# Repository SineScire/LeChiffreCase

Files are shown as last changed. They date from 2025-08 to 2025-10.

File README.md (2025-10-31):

<a href="https://github.com/SineScire/LeChiffreCase">LeChiffreCase</a> © 2025 by <a href="https://github.com/SineScire">SineNomen</a> is licensed under <a href="https://creativecommons.org/licenses/by-nc-sa/4.0/">CC BY-NC-SA 4.0</a>

# LeChiffreCase
A case for the Le Chiffre keyboard with a gasket mounted switchplate

There are multiple versions of the gaskets:
* Soft: Switchplate flexes with the press of a single key
* Medium: Switchplate flexes with the press of multiple keys
* Hard: Switchplate hardly flexes with the press of multiple keys

Check out the manual [here](https://github.com/SineScire/LeChiffreCase/blob/709f2b51f192e5b002fa32b0e5fa310748ea253c/Manual.md)

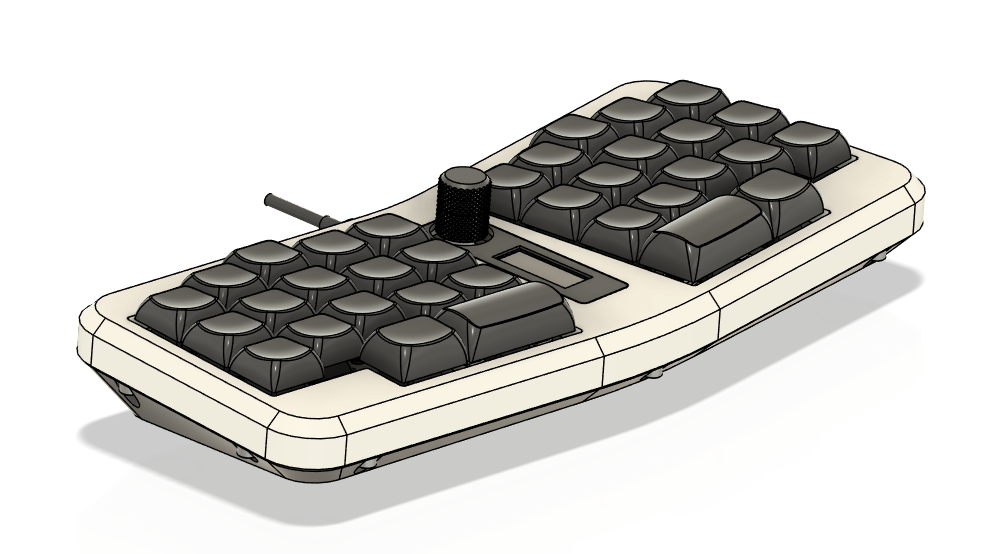
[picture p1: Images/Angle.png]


## Credits
* [Tominabox1](https://github.com/tominabox1/Le-Chiffre-Keyboard) for the original PCB design
* [Sporkus](https://github.com/sporkus/le_chiffre_keyboard_stm32) for the stm32F072 PCB design
* [Keycapsss](https://keycapsss.com/) for providing the PCB

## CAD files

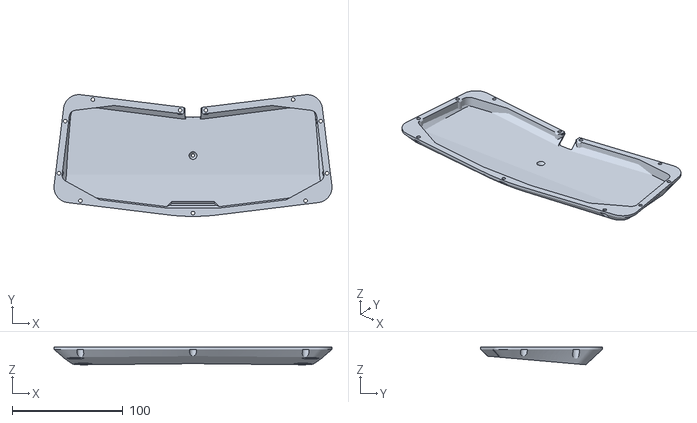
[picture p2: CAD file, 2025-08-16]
Files/BottomHousing.stl
251.0 x 110.0 x 15.9

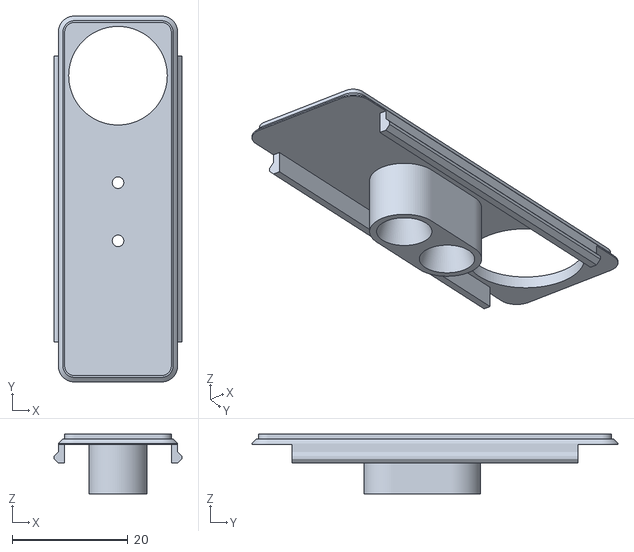
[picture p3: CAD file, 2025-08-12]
Files/InsertKnobLights.stl
22.0 x 63.1 x 10.3

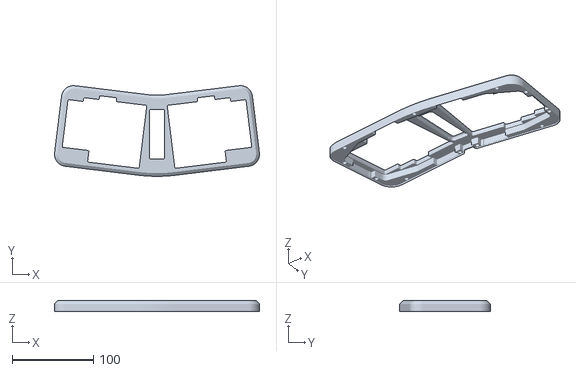
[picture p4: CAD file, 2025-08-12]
Files/TopHousing.stl
253.0 x 111.9 x 13.0

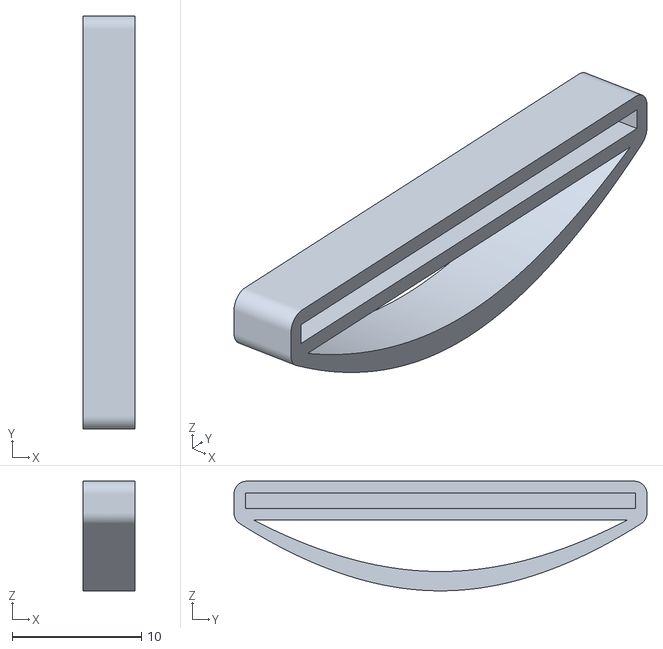
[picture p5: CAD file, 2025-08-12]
Files/GasketSoft.stl
4.00 x 32.0 x 8.50

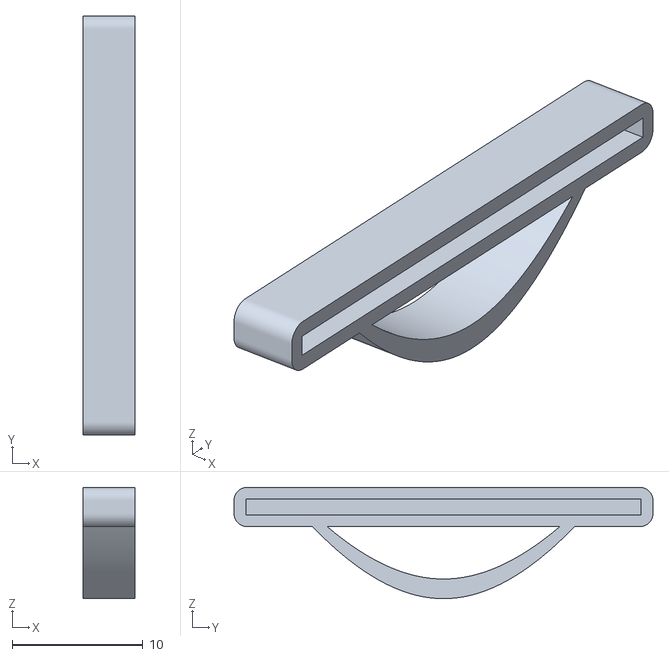
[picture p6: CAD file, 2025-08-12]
Files/GasketHard.stl
4.00 x 32.0 x 8.50

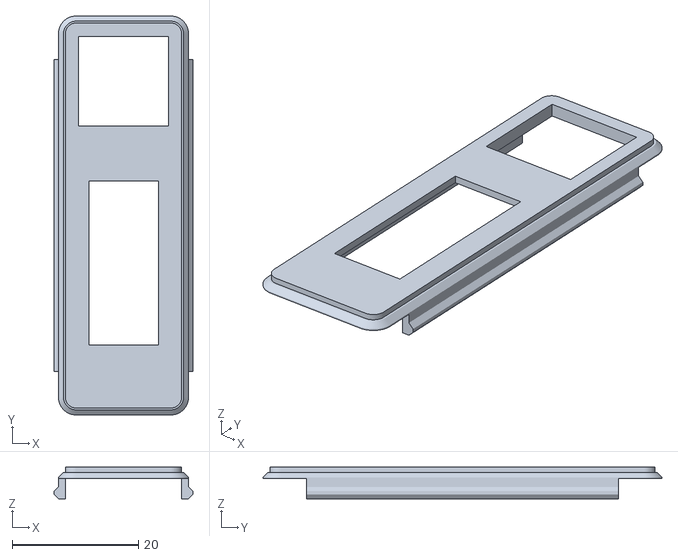
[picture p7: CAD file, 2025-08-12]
Files/InsertSwitchScreen.stl
22.0 x 63.1 x 5.00

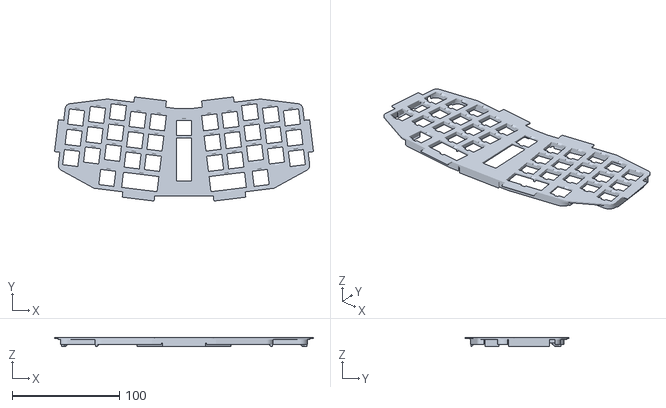
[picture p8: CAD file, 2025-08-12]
Files/Switchplate.stl
241.4 x 97.1 x 8.10

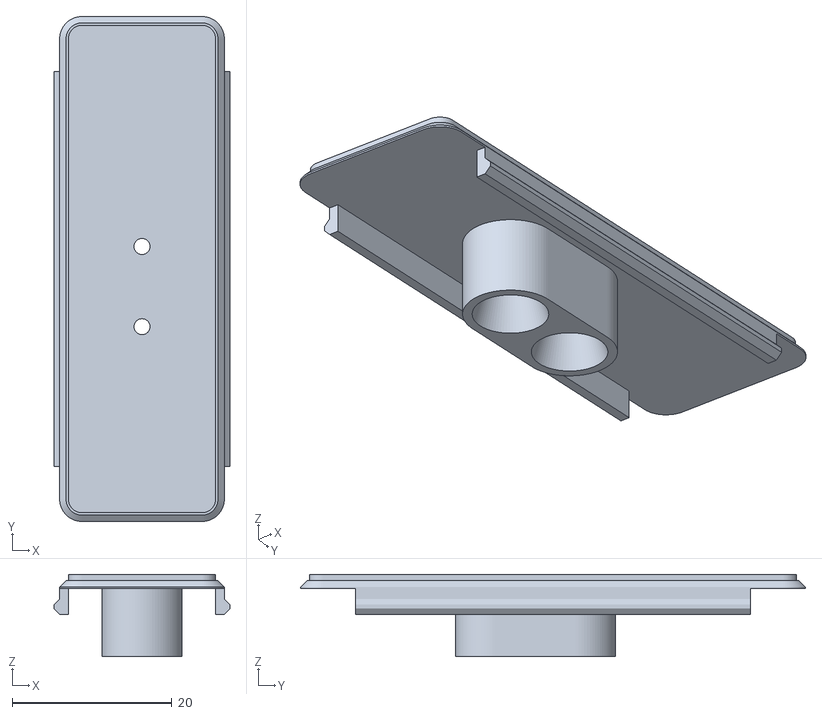
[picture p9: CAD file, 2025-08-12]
Files/InsertLights.stl
22.0 x 63.1 x 10.3

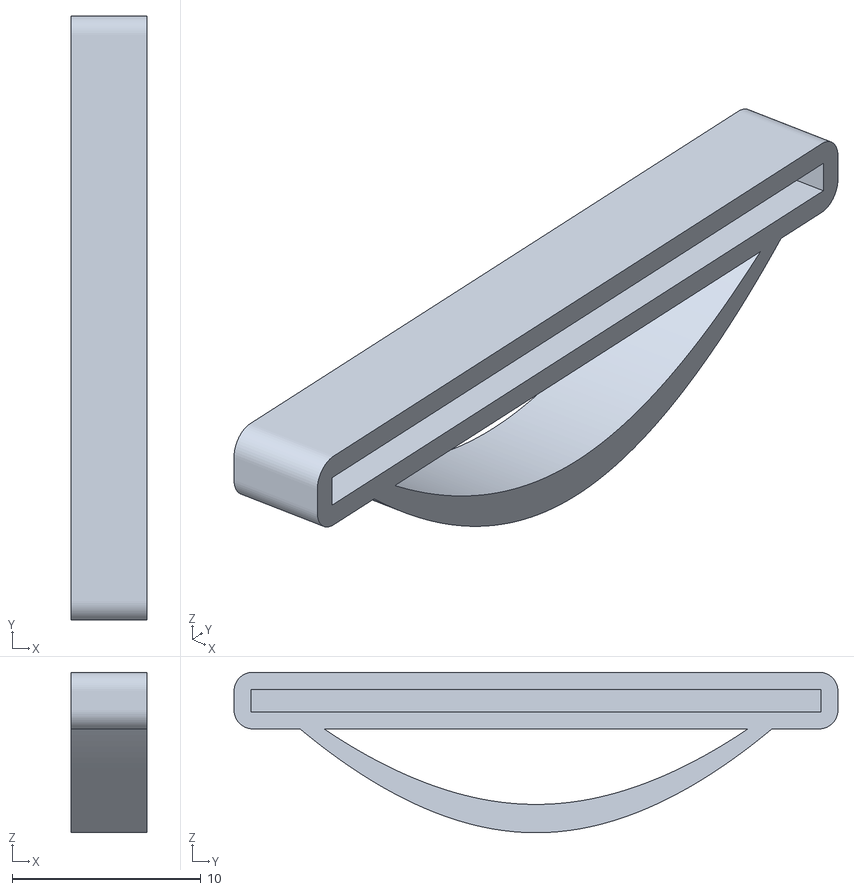
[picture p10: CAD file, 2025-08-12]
Files/GasketMedium.stl
4.00 x 32.0 x 8.50

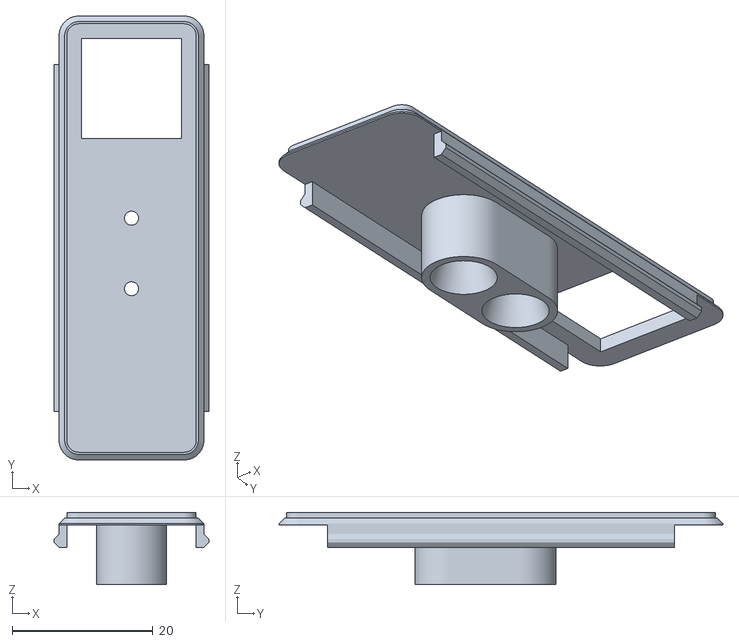
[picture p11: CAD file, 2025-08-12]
Files/InsertSwitchLights.stl
22.0 x 63.1 x 10.3

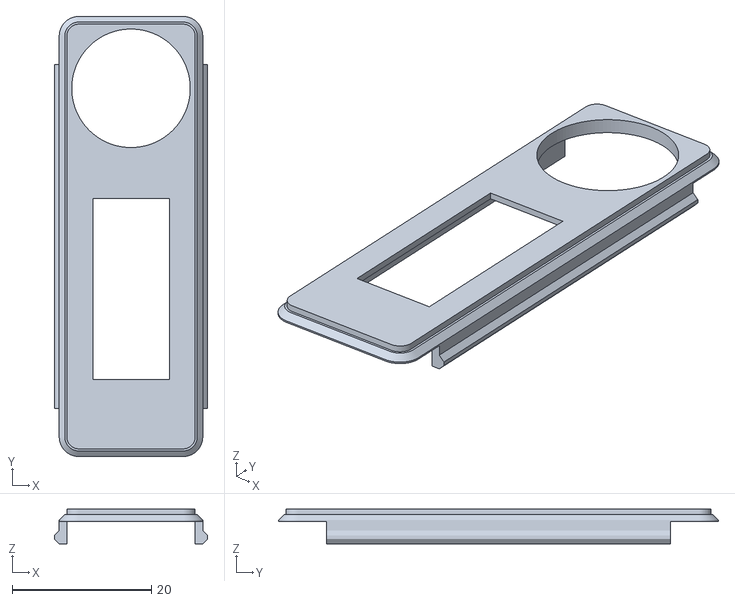
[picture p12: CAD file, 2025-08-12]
Files/InsertKnobScreen.stl
22.0 x 63.1 x 5.00

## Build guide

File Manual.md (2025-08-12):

## BOM

| Part | Quantity | Description |
| ---- | --- | --- |
| Top Housing | 1x | 3D printed part |
| Bottom Housing | 1x | 3D printed part | 
| Switchplate | 1x | 3D printed part | 
| Insertplate | 1x | A window plate for the screen/knob/lights |
| Gaskets | 6x | 3D printed with flexible filament around 95A hardness |
| m3x4mm Threaded Insert | 11x | Brass inserts for the top housing |
| m3x6mm Sockethead Screws | 11x | To fasten the top and bottom housing |
| Rubber feet | 4x | 2mm thick rubber feet with a diameter of 15mm |
| Soldering iron | 1x | To insert the threaded inserts |

## Printing the parts
* Suggested printing orientation for the parts
* The gaskets are printed with flexible filament with a hardness around 95A
* No supports should be needed to print these parts

| Top housing | Bottom housing | Switchplate |
| --- | --- | --- |
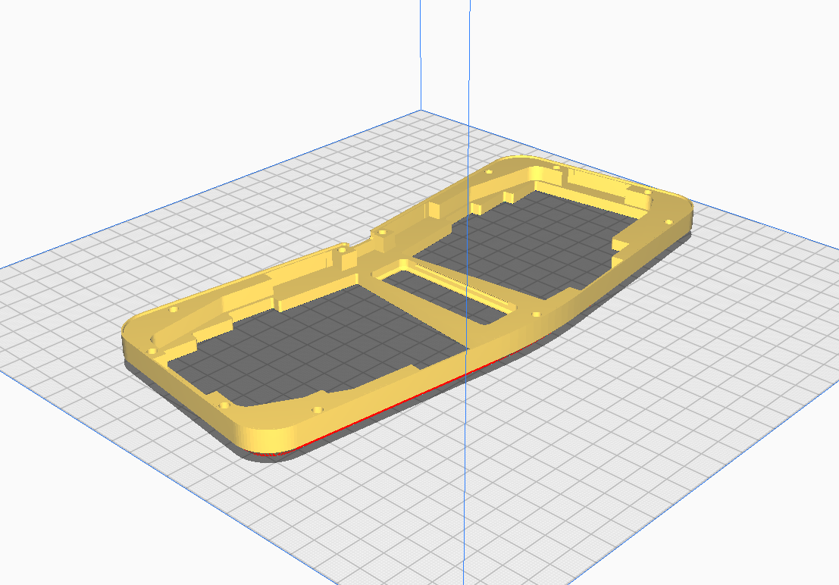
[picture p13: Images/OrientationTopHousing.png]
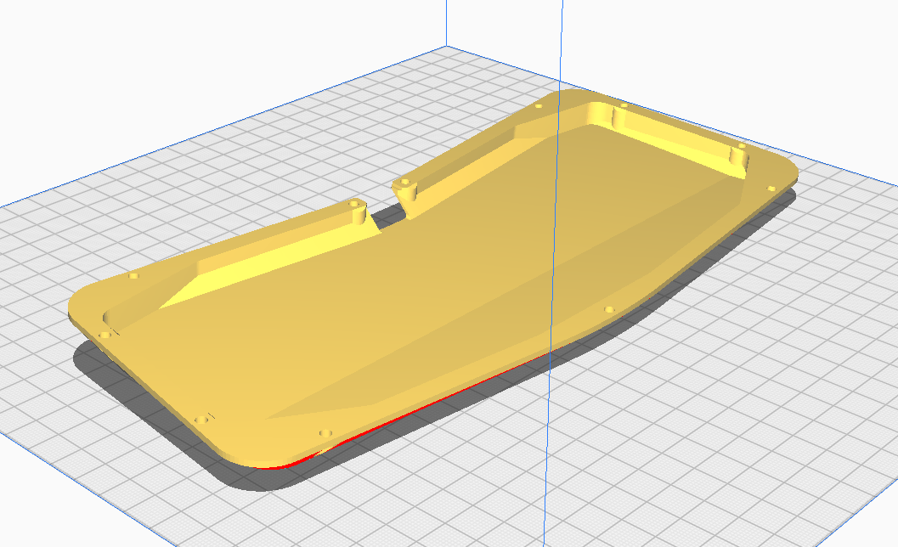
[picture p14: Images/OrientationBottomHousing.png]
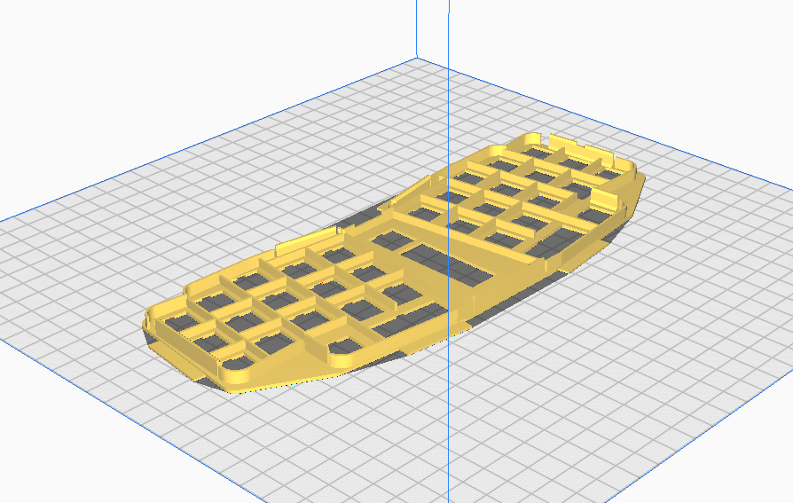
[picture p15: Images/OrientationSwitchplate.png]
|  |  |  |

| Insert plate | Gasket |
| --- | --- |
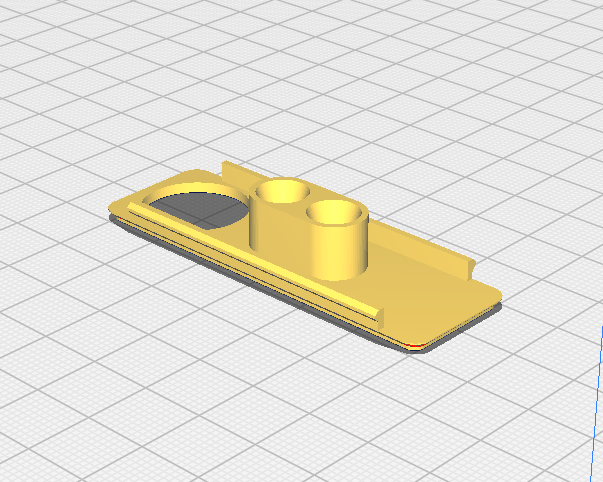
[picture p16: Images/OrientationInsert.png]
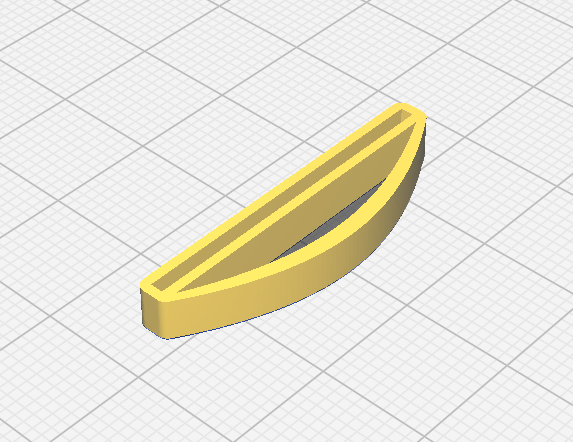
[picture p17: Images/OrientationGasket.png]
|  |  |

## Assembling the case
### Preparing the switchplate
1. Assemble the switchplate by snapping the PCB to the switchplate. The snap-fit joints on the switchplate are fragile, do not bend these or they might break. If more room is needed use the gasket mounts to bend the switchplate slightly to manouvre the PCB in place.
2. Place the six gaskets on the gasketmounts surrounding the switchplate.
3. Assemble the switchplate further with the switches of choice (and screen if used)
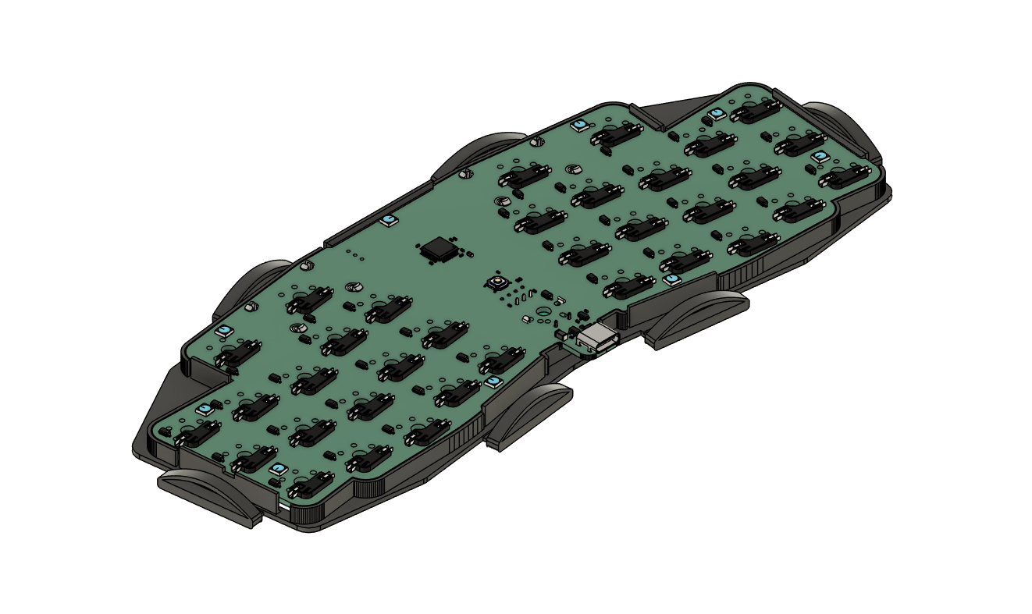
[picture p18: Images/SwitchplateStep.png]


### Preparing the top housing
1. Place the top housing face down and use a soldering iron to insert the eleven m3x4mm threaded inserts into the blue highlighted holes.
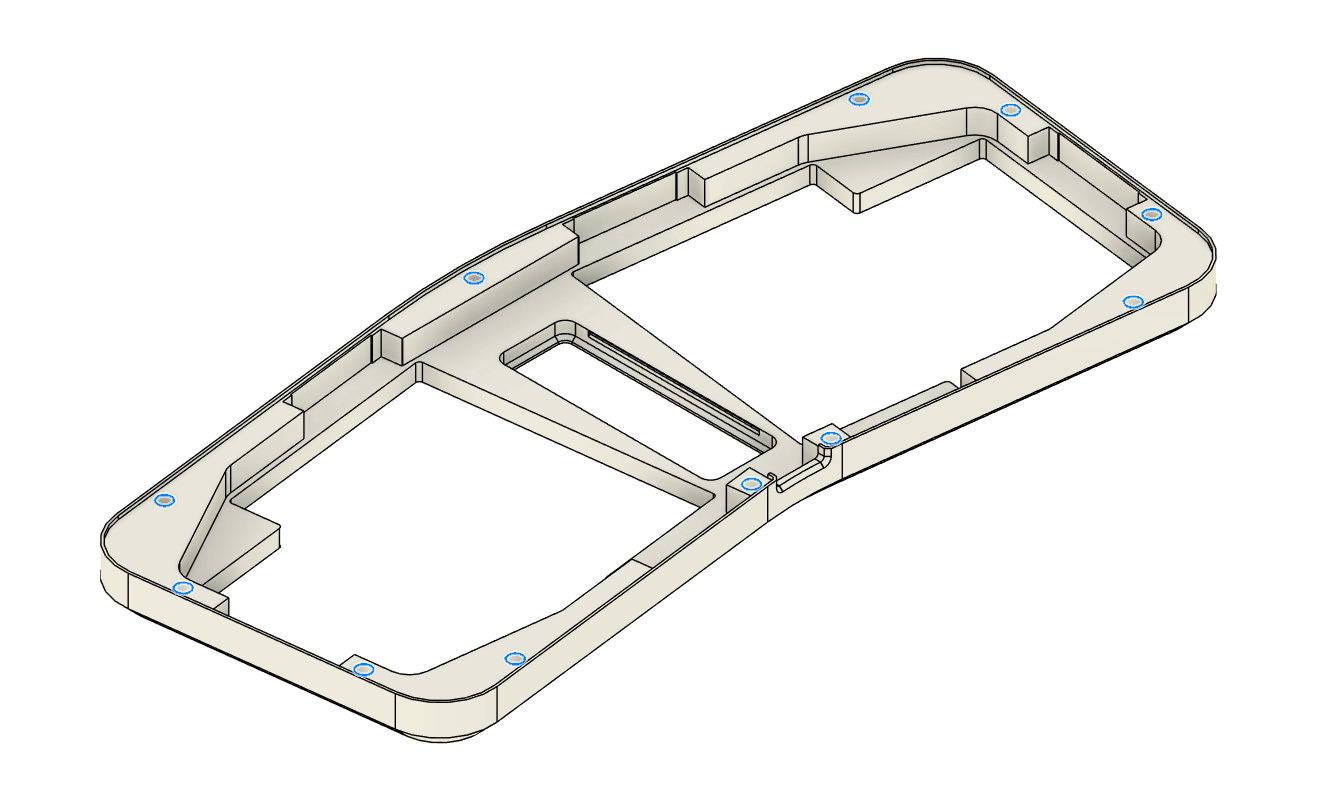
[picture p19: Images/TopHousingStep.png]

2. Depending on if you want to use the Le Chiffre with or withough a knob, screen or extra button, snap the corresponding window insert plate via the underside of the top housing into place. The insert plate should sit flush with the top housing.

| Insert plate in place | Different types of insert plates |
| --- | --- |
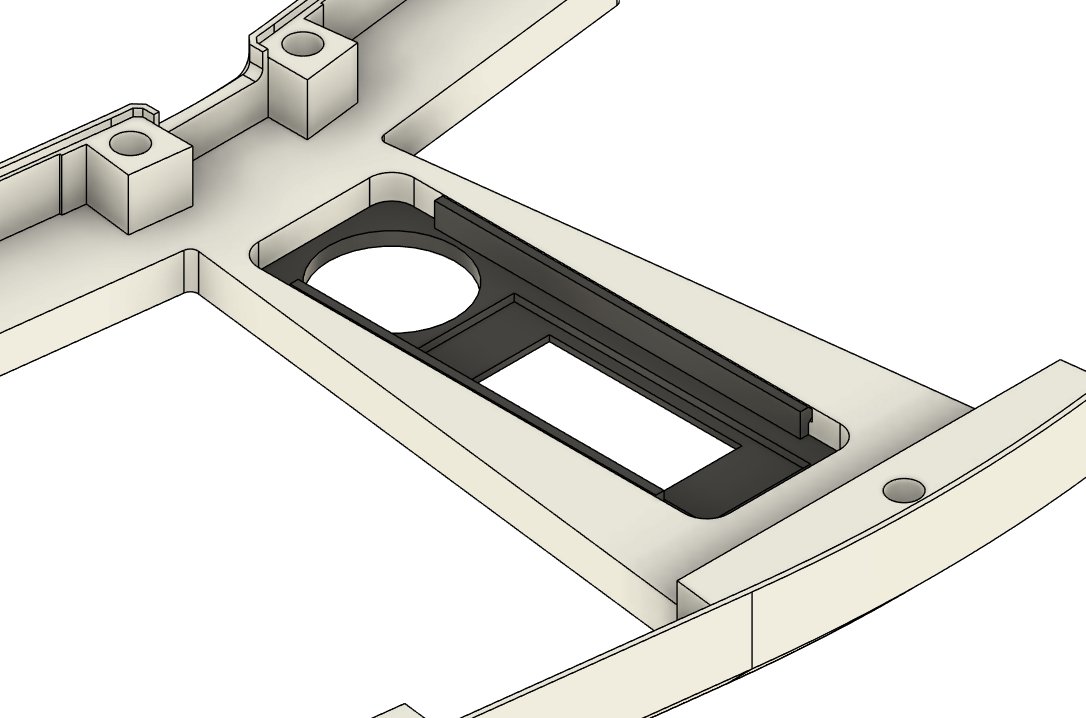
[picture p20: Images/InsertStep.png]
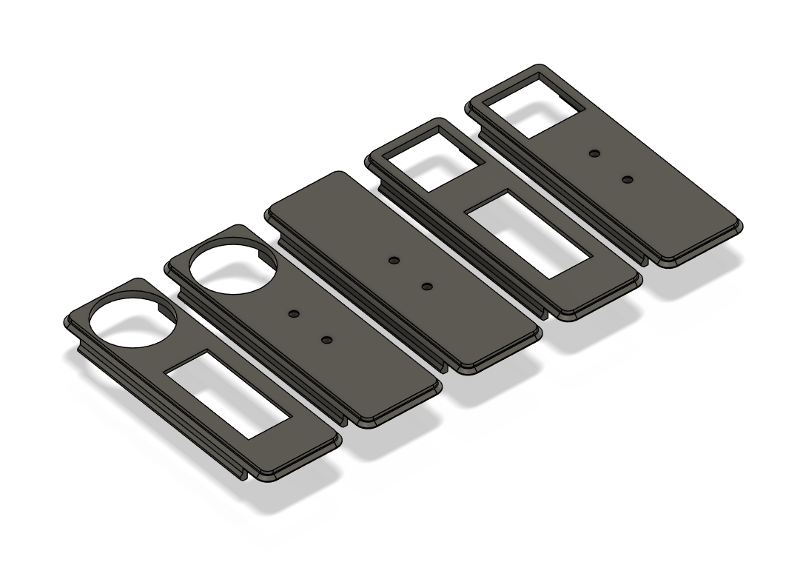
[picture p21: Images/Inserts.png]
|  |  |

#### Assembling the case
1. Place the assembled switchplate in the top housing and set it face down, the gaskets should not fit snug in the top housing but there also should not be any sideways movement.
2. Assemble the case by placing the bottom housing on the top housing and fasten the case using the eleven m3x6mm sockethead screws.
3. Place the four rubber feet on the bottom housing
4. The case is now assembled! Finish the build with your keycaps of choise and enjoy your keyboard!
